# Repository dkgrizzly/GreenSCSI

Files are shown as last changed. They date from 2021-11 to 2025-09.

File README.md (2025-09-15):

# GreenSCSI
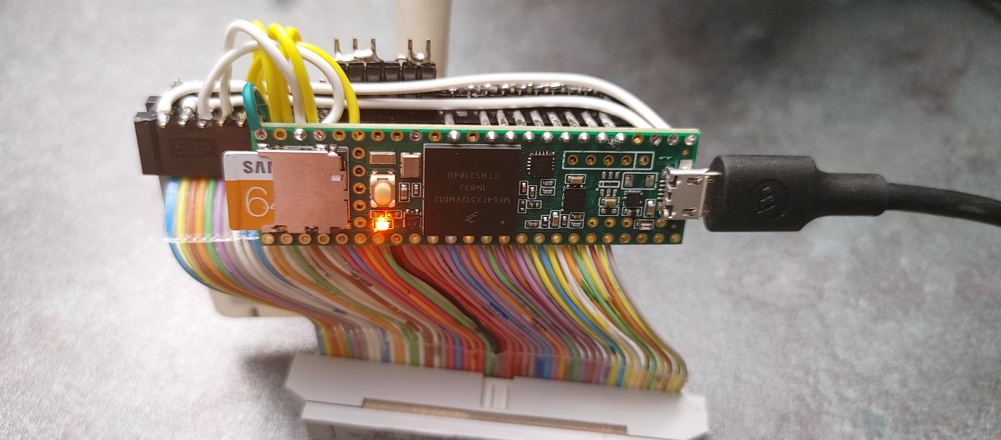
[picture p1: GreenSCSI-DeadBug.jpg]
DeadBug assembly of a Teensy 3.5 directly on a 50 pin SCSI header! GreenSCSI Teensy 3.5 Dead Bug


GreenSCSI, BlueSCSI & ArdSCSino are hardware that reproduce SCSI devices (hard disks) with Arduino like devices.

`GreenSCSI` created by https://github.com/dkgrizzly [dkgrizzly] is a fork of `BlueSCSI` which adds:

* Teensy 3.5 (Kinetis K64...) support
* Better LUN handling

`BlueSCSI` created by https://github.com/erichelgeson [erichelgeson] is a fork of `ArdSCSino-stm32`

`ArdSCSino-stm32` created by https://github.com/ztto/ArdSCSino-stm32 [ztto] is the STM32 version of `ArdSCSino`

`ArdSCSino` created by https://twitter.com/h_koma2 [Tambo (TNB Seisakusho)]

Build against LittleFS commit a061862589841627424170a12a246ce5660a4f0a if using Arduino 1.8.19 and Teensyduino 1.8.5

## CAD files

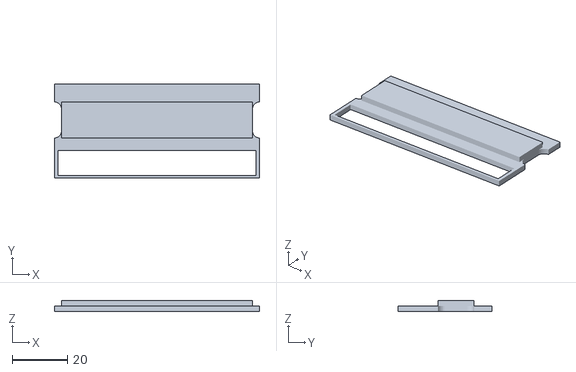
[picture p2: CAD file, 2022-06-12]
case/GreenSCSI-top.stl
74.0 x 34.0 x 4.00

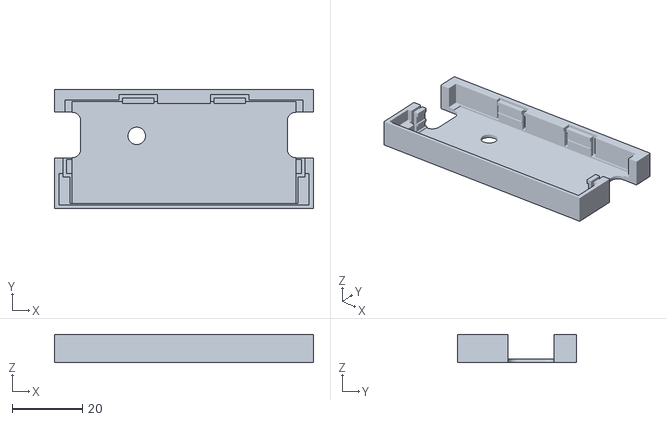
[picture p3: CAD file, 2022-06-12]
case/GreenSCSI-bottom.stl
74.0 x 34.0 x 8.00

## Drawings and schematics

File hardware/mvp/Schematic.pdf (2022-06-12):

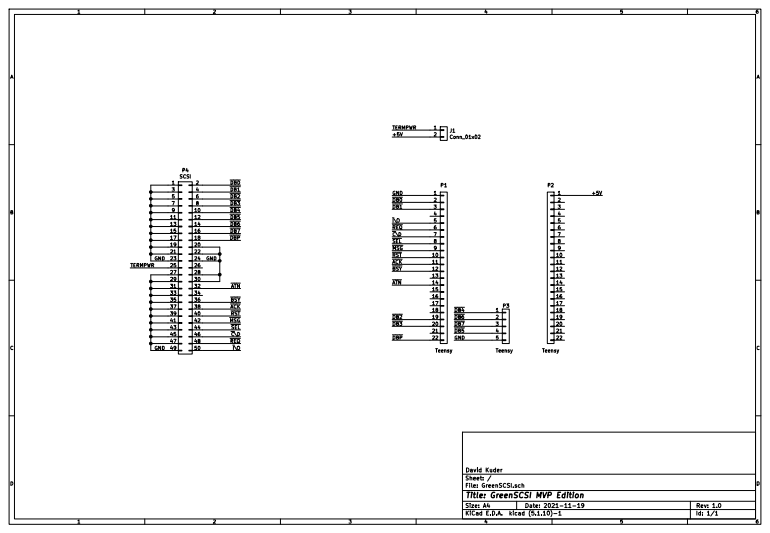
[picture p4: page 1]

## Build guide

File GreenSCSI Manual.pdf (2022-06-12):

# GreenSCSI

# Reference Manual

Revision 0001 - 1/1/2022
Copyright (C) 2022 David Kuder

## Thank you for your purchase of a GreenSCSI Kit!

## At a time when mainstream vendors have dropped commercial

support and products on the market were cost prohibitive,

## a community has sprung up to provide storage solutions on SCSI and other vintage disk interfaces. We’re glad to be part of that community and provide inexpensive options

for enthusiasts in need.

## GreenSCSI wouldn’t be here without the work of the

BlueSCSI, RaSCSI, TinySCSIEmu, and SCSI2SD projects.

Your support means that we can keep doing what we love,

## keeping old computers working and fun!

## -David Kuder

GreenSCSI | Preface

I

II

# Section 1 - Hardware Assembly

## Parts and Tools checklist | Page 1 Soldering the kit | Page 2

# Section 2 - Testing your GreenSCSI

## Loopback plug installation | Page 5 Test procedure | Page 6

# Section 3 - microSD Card Setup

## Formatting the microSD Card | Page 9 Interactive Configuration | Page 10 Configuration Reference | Page 11

# Appendix A - Troubleshooting

GreenSCSI | Table of Contents

# III

IV

With your GreenSCSI Kit you should have recieved the parts listed below. Please check your kit’s contents and make sure all parts are present.

❒ GreenSCSI Board
❒ Teensy 3.5
❒ 50 Pin SCSI Connector
❒ SCSI Loop-Back Test Plug

You will need some tools and materials to assemble the kit:

❒ Soldering Iron (Temperature controlled preferred)
❒ Solder (ChipQuik and sparkfun are two of our favorite brands) ❒ Isopropyl Alcohol (For removing flux after soldering)

Some items that will also come in handy:

❒ USB Micro-B Cable
❒ USB microSD Reader

Depending on which version of the kit you purchased, you may have recieved a microSD card preloaded with an example configuration and some blank drive images.

Section 3 in this manual details the creation of such a card for use with GreenSCSI, including the creation of blank disk images and configuration via greenscsi.cfg or the interactive console.

GreenSCSI | Hardware Assembly

Step 1.

Pre-heat your soldering iron. Typically a temperature of 320’C or 608’F is used.
Once your iron is at temperature it is a good idea to clean the tip with a brass sponge to remove any residue from previous jobs.
Step 2.

Use the included header pins to align the corners of the Teensy 3.5 board with the matching footprint on the GreenSCSI board. The pads on the back of the Teensy 3.5 should be aligned with the oblong cut outs in the GreenSCSI board and there should be no gap between the boards.

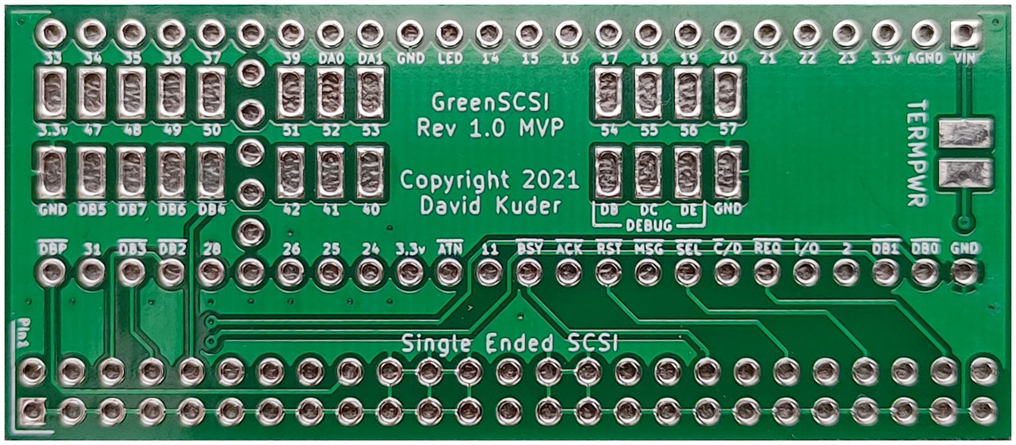
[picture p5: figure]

[ Picture 1 - GreenSCSI Board Bottom Side ]

Step 3.

When you have the pads aligned in the slots you can heat the pad and the slot with the iron and begin flowing in solder. You may need to carefully scrape the pad with your iron as you start for the solder to begin adhering to the pad. At a minimum you need to solder the connections labeled DB4, DB5, DB6, and DB7. Any locations labeled with only numbers are unused pins in the design which you are free to use for adding functionality to the GreenSCSI. You can reference the “Welcome to Teensy 3.5” card included in your kit for what functions are available on each pin.

[ Picture 2 - Soldering DB5 ]

GreenSCSI | Hardware Assembly

Step 4.

With the DB4 - DB7 pads soldered, you should now be able to remove the pins used to align the boards in step 2. Solder the remaining named locations starting with VIN and DBP working your way around to not create a concentration of heat in any one area. A 10 cm length of bare wire is included in the kit to make soldering of the through holes easier. Cut the wire flush after soldering each connection.

[ Picture 3 - Soldering DBP ]

Step 5.

Align the 50 pin male SCSI connector in the holes provided. Pin 1 on the SCSI connector is marked with an arrow and the alignment notch should face to the edge of the board.

[ Picture 4 - Soldering the SCSI connector ]

Next Section: Testing your GreenSCSI

GreenSCSI | Hardware Assembly
- ▶ ▶

You should now have an assembled GreenSCSI device, and are likely tempted to plug it in to your treasured vintage equipment - BUT WAIT! It is important to first test your GreenSCSI with the included LoopBack plug to ensure that all connections made during assembly are solid. This only takes a moment and saves you troubleshooting headaches later on.

[ Picture 5 - LoopBack installed ]

With the LoopBack plug installed and no microSD card inserted, connect your GreenSCSI to a modern computer with a USB Micro-B cable. Your computer should detect a USB Serial adapter and automatically configure it for use.

[ Picture 6 - USB Detection Bubble ]

GreenSCSI | Testing your GreenSCSI

Open up a terminal emulator and connect to the new serial port that was just installed. We recommend using Tera Term on Windows computers.

[ Picture 7 - Tera Term ]

Press ENTER on your keyboard and you should see a | / $ _ | prompt appear.
Type loopbacktest and press ENTER. The GreenSCSI firmware will run several tests to ensure that the SCSI bus connections are correct and free from any faults. When directed, remove the loopback plug and press ENTER to complete the final tests. You will get a test report similar to the one shown below.

[ Picture 8 - Loop Back Test Report ]

If all went well you should now be ready to move on to configuring your microSD card.
If there were any faults found, double check the soldering as directed by the test report.

Next Section: microSD card Setup

GreenSCSI | Testing your GreenSCSI
- ▶ ▶

Your GreenSCSI supports truly massive storage compared to the vintage systems you are likely to be using it with. The choice is yours as to the size of microSD card to use. We have tested 32GB, 64GB, 128GB, and 256GB cards from Samsung and found them to function well with the GreenSCSI hardware and firmware. In order to support disk images over 2GB in size, your microSD card should be formatted with the ExFAT filesystem.

Now that your card is formatted, you can create a greenscsi.cfg file using either the interactive console present in the firmware of the GreenSCSI device, or by hand with a text editor on your modern computer.

GreenSCSI | microSD card Setup

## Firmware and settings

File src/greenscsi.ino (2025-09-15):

/*  
 *  GreenSCSI
 *  Copyright (c) 2021  David Kuder
 *  
 *  Based on BlueSCSI
 *  Copyright (c) 2021  Eric Helgeson, Androda
 *  
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
 * This file incorporates work covered by the following copyright and  
 * permission notice:  
 *  
 *     Copyright (c) 2019 komatsu   
 *  
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
 *     THE SOFTWARE IS PROVIDED "AS IS" AND THE AUTHOR DISCLAIMS ALL  
 *     WARRANTIES WITH REGARD TO THIS SOFTWARE INCLUDING ALL IMPLIED  
 *     WARRANTIES OF MERCHANTABILITY AND FITNESS. IN NO EVENT SHALL THE  
 *     AUTHOR BE LIABLE FOR ANY SPECIAL, DIRECT, INDIRECT, OR  
 *     CONSEQUENTIAL DAMAGES OR ANY DAMAGES WHATSOEVER RESULTING FROM LOSS  
 *     OF USE, DATA OR PROFITS, WHETHER IN AN ACTION OF CONTRACT,  
 *     NEGLIGENCE OR OTHER TORTIOUS ACTION, ARISING OUT OF OR IN  
 *     CONNECTION WITH THE USE OR PERFORMANCE OF THIS SOFTWARE.  
 */

#include <Arduino.h> // For Platform.IO
#include <SPI.h>
#include <LittleFS.h>
#include <SdFat.h>
#include "sdios.h"
#include "config.h"
#include "scsi_defs.h"
#include "cmd.h"

// SDFAT
SdFs sd;
LittleFS_Program lfs;


struct part_s {
  uint8_t boot;
  uint8_t beginCHS[3];
  uint8_t type;
  uint8_t endCHS[3];
  uint32_t firstSector;
  uint32_t totalSectors;
} __attribute__((packed));
typedef struct part_s part_t;
//-----------------------------------------------------------------------------
struct mbr_s {
  uint8_t   bootCode[446];
  part_t part[4];
  uint8_t   signature[2];
} __attribute__((packed));
typedef struct mbr_s mbr_t;

boolean debuglog = 0;

#if DEBUG == 1
#define LOG(XX)      if(debuglog) Serial.print(XX)
#define LOGHEX2(XX)  if(debuglog) Serial.printf("%02x", XX)
#define LOGHEX4(XX)  if(debuglog) Serial.printf("%04x", XX)
#define LOGHEX6(XX)  if(debuglog) Serial.printf("%06x", XX)
#define LOGHEX8(XX)  if(debuglog) Serial.printf("%08x", XX)
#define LOGN(XX)     if(debuglog) Serial.println(XX)
#define LOGHEX2N(XX) if(debuglog) Serial.printf("%02x\r\n", XX)
#define LOGHEX4N(XX) if(debuglog) Serial.printf("%04x\r\n", XX)
#define LOGHEX6N(XX) if(debuglog) Serial.printf("%06x\r\n", XX)
#define LOGHEX8N(XX) if(debuglog) Serial.printf("%08x\r\n", XX)
#elif DEBUG == 2
#define LOG(XX)      LOG_FILE.print(XX); LOG_FILE.sync();
#define LOGHEX2(XX)  LOG_FILE.printf("%02x", XX); LOG_FILE.sync();
#define LOGHEX4(XX)  LOG_FILE.printf("%04x", XX); LOG_FILE.sync();
#define LOGHEX6(XX)  LOG_FILE.printf("%06x", XX); LOG_FILE.sync();
#define LOGHEX8(XX)  LOG_FILE.printf("%08x", XX); LOG_FILE.sync();
#define LOGN(XX)     LOG_FILE.println(XX); LOG_FILE.sync();
#define LOGHEX2N(XX) LOG_FILE.printf("%02x\r\n", XX); LOG_FILE.sync();
#define LOGHEX4N(XX) LOG_FILE.printf("%04x\r\n", XX); LOG_FILE.sync();
#define LOGHEX6N(XX) LOG_FILE.printf("%06x\r\n", XX); LOG_FILE.sync();
#define LOGHEX8N(XX) LOG_FILE.printf("%08x\r\n", XX); LOG_FILE.sync();
#else
#define LOG(XX)      //Serial.print(XX)
#define LOGHEX2(XX)  //Serial.printf("%02x", XX)
#define LOGHEX4(XX)  //Serial.printf("%04x", XX)
#define LOGHEX6(XX)  //Serial.printf("%06x", XX)
#define LOGHEX8(XX)  //Serial.printf("%08x", XX)
#define LOGN(XX)     //Serial.println(XX)
#define LOGHEX2N(XX) //Serial.printf("%02x\r\n", XX)
#define LOGHEX4N(XX) //Serial.printf("%04x\r\n", XX)
#define LOGHEX6N(XX) //Serial.printf("%06x\r\n", XX)
#define LOGHEX8N(XX) //Serial.printf("%08x\r\n", XX)
#endif

#define DB0       0     // SCSI:DB0  Port B Bit 16
#define DB1       1     // SCSI:DB1  Port B Bit 17
#define DB2       29    // SCSI:DB2  Port B Bit 18
#define DB3       30    // SCSI:DB3  Port B Bit 19
#define DB4       43    // SCSI:DB4  Port B Bit 20
#define DB5       46    // SCSI:DB5  Port B Bit 21
#define DB6       44    // SCSI:DB6  Port B Bit 22
#define DB7       45    // SCSI:DB7  Port B Bit 23
#define DBP       32    // SCSI:DBP  Port B Bit 11

#define ATN       12    // SCSI:ATN  Port C Bit 7
#define BSY       10    // SCSI:BSY  Port C Bit 4
#define ACK       9     // SCSI:ACK  Port C Bit 3
#define RST       8     // SCSI:RST  Port D Bit 3
#define MSG       7     // SCSI:MSG  Port D Bit 2
#define SEL       6     // SCSI:SEL  Port D Bit 4
#define CD        5     // SCSI:C/D  Port D Bit 7
#define REQ       4     // SCSI:REQ  Port A Bit 13
#define IO        3     // SCSI:I/O  Port A Bit 12

#define SD_CS     BUILTIN_SDCARD      // SDCARD:CS
#define LED       13     // LED  Port C Bit 5

// LED control
#define LED_ON()       { GPIOC_PSOR = (1 << 5); }
#define LED_OFF()      { GPIOC_PCOR = (1 << 5); }

#define SET_REQ_ACTIVE()    { GPIOA_PCOR = (1 << 13); }
#define SET_REQ_INACTIVE()  { GPIOA_PSOR = (1 << 13); }
//#define SET_MSG_ACTIVE()    { GPIOD_PCOR = (1 << 2); __asm__("nop""\n\t""nop""\n\t"); }
//#define SET_MSG_INACTIVE()  { GPIOD_PSOR = (1 << 2); __asm__("nop""\n\t""nop""\n\t"); }
//#define SET_CD_ACTIVE()     { GPIOD_PCOR = (1 << 7); __asm__("nop""\n\t""nop""\n\t"); }
//#define SET_CD_INACTIVE()   { GPIOD_PSOR = (1 << 7); __asm__("nop""\n\t""nop""\n\t"); }
//#define SET_IO_ACTIVE()     { GPIOA_PCOR = (1 << 12); __asm__("nop""\n\t""nop""\n\t"); }
//#define SET_IO_INACTIVE()   { GPIOA_PSOR = (1 << 12); __asm__("nop""\n\t""nop""\n\t"); }

//#define SET_REQ_ACTIVE()     { pinMode(REQ, OUTPUT_OPENDRAIN);  digitalWrite(REQ, LOW); }
//#define SET_REQ_INACTIVE()   { digitalWrite(REQ, HIGH); pinMode(REQ, INPUT); }
#define SET_MSG_ACTIVE()     { pinMode(MSG, OUTPUT_OPENDRAIN); digitalWrite(MSG, LOW); }
#define SET_MSG_INACTIVE()   { digitalWrite(MSG, HIGH); pinMode(MSG, INPUT); }
#define SET_CD_ACTIVE()     { pinMode(CD, OUTPUT_OPENDRAIN);  digitalWrite(CD, LOW); }
#define SET_CD_INACTIVE()   { digitalWrite(CD, HIGH); pinMode(CD, INPUT); }
#define SET_IO_ACTIVE()     { pinMode(IO, OUTPUT_OPENDRAIN); digitalWrite(IO, LOW); }
#define SET_IO_INACTIVE()   { digitalWrite(IO, HIGH); pinMode(IO, INPUT); }
//#define SET_BSY_ACTIVE()     { pinMode(BSY, OUTPUT_OPENDRAIN); digitalWrite(BSY, LOW); }
//#define SET_BSY_INACTIVE()   { digitalWrite(BSY, HIGH); pinMode(BSY, INPUT); }

#define SET_BSY_ACTIVE()   { GPIOC_PCOR = (1 << 4); __asm__("nop""\n\t"); }
#define SET_BSY_INACTIVE() { GPIOC_PSOR = (1 << 4); }

#define GET_ACK() (!(GPIOC_PDIR & (1 << 3)))
#define GET_ATN() (!(GPIOC_PDIR & (1 << 7)))
#define GET_BSY() (!(GPIOC_PDIR & (1 << 4)))
#define GET_RST() (!(GPIOD_PDIR & (1 << 3)))
#define GET_SEL() (!(GPIOD_PDIR & (1 << 4)))

// Initiator Mode
#define SET_ACK_ACTIVE()   { GPIOC_PCOR = (1 << 3); __asm__("nop""\n\t"); }
#define SET_ACK_INACTIVE() { GPIOC_PSOR = (1 << 3); }
#define SET_ATN_ACTIVE()   { GPIOC_PCOR = (1 << 7); __asm__("nop""\n\t"); }
#define SET_ATN_INACTIVE() { GPIOC_PSOR = (1 << 7); }
#define SET_RST_ACTIVE()   { GPIOD_PCOR = (1 << 3); __asm__("nop""\n\t"); }
#define SET_RST_INACTIVE() { GPIOD_PSOR = (1 << 3); }
#define SET_SEL_ACTIVE()   { GPIOD_PCOR = (1 << 4); __asm__("nop""\n\t"); }
#define SET_SEL_INACTIVE() { GPIOD_PSOR = (1 << 4); }

#define GET_MSG() (!(GPIOD_PDIR & (1 << 2)))
#define GET_CD()  (!(GPIOD_PDIR & (1 << 7)))
#define GET_IO()  (!(GPIOA_PDIR & (1 << 12)))
#define GET_REQ() (!(GPIOA_PDIR & (1 << 13)))

// Turn on the output only for BSY
// BSY,REQ,MSG,CD,IO Turn on the output (no change required for OD)
#define SCSI_TARGET_ACTIVE()   { }
// BSY,REQ,MSG,CD,IO Turn off output
#define SCSI_TARGET_INACTIVE() { SCSI_DB_INPUT(); SET_REQ_INACTIVE(); SET_MSG_INACTIVE(); SET_CD_INACTIVE(); SET_IO_INACTIVE(); SET_BSY_INACTIVE(); }

#define SCSI_INITIATOR_INACTIVE() { SCSI_DB_INPUT(); SET_SEL_INACTIVE(); SET_ACK_INACTIVE(); SET_ATN_INACTIVE(); SET_RST_INACTIVE(); }

#define SCSI_DB_MASK 0x00ff0800


// HDImage file
#define HDIMG_ID_POS  2                 // Position to embed ID number
#define HDIMG_LUN_POS 3                 // Position to embed LUN numbers
#define HDIMG_BLK_POS 5                 // Position to embed block size numbers
#define MAX_FILE_PATH 32                // Maximum file name length

typedef struct m_sense_s {
  uint8_t     m_key;
  uint8_t     m_code;
  uint8_t     m_key_specific[4];
} msense_t;

typedef void (*CommandHandler_t)();
CommandHandler_t m_badlunhandler[256];

// VirtualDevice
typedef struct VirtualDevice_s
{
  boolean     m_enabled;
  uint8_t     m_id;
  uint8_t     m_lun;
  uint8_t     m_type;                 // Device Type
  char        m_filename[MAX_FILE_PATH+1];
  FsFile      m_file;                 // File object
  uint64_t    m_fileSize;             // File size
  uint8_t     m_sectors;
  uint8_t     m_heads;
  uint32_t    m_cylinders;
  size_t      m_blocksize;            // SCSI BLOCK size
  uint32_t    m_firstSector;          // First sector for partition
  boolean     m_rawPart;              // Raw Partition (True) or Image File (False)
#if SUPPORT_TAPE
  size_t      m_filemarks;            // Tape position counter (file marks since BOM)
#endif
  uint8_t     m_inquiryresponse[SCSI_INQUIRY_RESPONSE_SIZE];
  CommandHandler_t m_handler[256];
  msense_t    m_sense;
  uint16_t    m_quirks;
} VirtualDevice_t;

VirtualDevice_t  m_vdev[NUM_VDEV];    // Maximum number
uint8_t       m_vdevcnt = 0;          // Number of allocated vdevs
uint8_t       m_vdevmap[NUM_SCSIID][NUM_SCSILUN]; // Map ID/LUN to a vdev

volatile bool m_isBusReset = false;   // Bus reset

uint8_t       scsi_id_mask;           // Mask list of responding SCSI IDs
uint8_t       m_id;                   // Currently responding SCSI-ID
uint8_t       m_lun;                  // Logical unit number currently responding
uint8_t       m_sts;                  // Status uint8_t
uint8_t       m_msg;                  // Message uint8_ts
VirtualDevice_t *m_sel;               // VirtualDevice for current SCSI-ID, LUN
uint8_t       m_buf[MAX_BLOCKSIZE+1]; // General purpose buffer + overrun fetch
int           m_msc;
uint8_t       m_msb[256];             // Command storage uint8_ts
uint8_t       m_cmdlen;
uint8_t       m_cmd[12];
uint8_t       m_responsebuffer[256];
uint16_t      default_quirks = (SUPPORT_SASI_DEFAULT ? QUIRKS_SASI : 0) | (SUPPORT_APPLE_DEFAULT ? QUIRKS_APPLE : 0);
uint16_t ledbits = 0;
uint8_t ledbit = 0;

uint8_t cardMBR[512];

typedef enum {
  PHASE_BUSFREE = 0,
  PHASE_SELECTION,
  PHASE_MESSAGEOUT,
  PHASE_COMMAND,
  PHASE_STATUSIN,
  PHASE_MESSAGEIN,
} phase_t;
phase_t       m_phase = PHASE_BUSFREE;

// Log File
#define VERSION "1.4-20230529"
#if DEBUG == 2
#define LOG_FILENAME "LOG.txt"
FsFile LOG_FILE;
#endif


void onBusReset(void);
void initFileLog(void);
void finalizeFileLog(void);

/*
 * IO read.
 */
inline uint8_t readIO(void)
{
  // Port input data register
  uint32_t ret = ~GPIOB_PDIR;
  //uint8_t bret = ret >> 16;
#if READ_PARITY_CHECK
  if((db_bsrr[bret] ^ ret) & 0x0800)
    m_sts |= 0x01; // parity error
#endif

  return ret >> 16; //bret;
}

boolean OpenImage(VirtualDevice_t *h, const char *image_name)
{
  h->m_fileSize = 0;
  h->m_file = sd.open(image_name, O_RDWR);
  if(h->m_file.isOpen()) {
    h->m_fileSize = h->m_file.size();
    h->m_cylinders = (uint32_t)((uint64_t)h->m_fileSize / ((uint64_t)h->m_blocksize * (uint64_t)h->m_heads * (uint64_t)h->m_sectors));

    return true; // File opened
  }
  return false;
}

#if SUPPORT_DISK or SUPPORT_OPTICAL
/*
 * Open HDD or CDROM image file
 */
boolean OpenDiskImage(VirtualDevice_t *h, const char *image_name, int blocksize)
{
  if(!strncmp(image_name, "/tgts/", 6)) {
    LOGN("/tgts/ path is not supported for disk images.");
    return false;
  }

  if(!strncmp(image_name, "/vdevs/", 7)) {
    LOGN("/vdevs/ path is not supported for disk images.");
    return false;
  }

  if(!strncmp(image_name, "/diag/", 6)) {
    LOGN("/diag/ path is not supported for disk images.");
    return false;
  }

  if(!strncmp(image_name, "/nv/", 4)) {
    LOGN("/nv/ path is not supported for disk images.");
    return false;
  }

  h->m_rawPart = false;

  if(!strncmp(image_name, "/raw/part", 9)) {
    int partIndex = image_name[9] - '0';
    mbr_t *mbr = (mbr_t *)cardMBR;
    if((partIndex < 0) || (partIndex > 3)) {
      LOGN("partition index is outside the allowed range.");
      return false;
    }

    sd.card()->readSector(0, cardMBR);
    if(mbr->part[partIndex].type != 0x87) {
      LOGN("partition is of the wrong type.");
      return false;
    }
    
    h->m_blocksize = blocksize;
    h->m_fileSize = ((uint64_t)mbr->part[partIndex].totalSectors) * ((uint64_t)512);
    h->m_cylinders = (uint32_t)((uint64_t)h->m_fileSize / ((uint64_t)h->m_blocksize * (uint64_t)h->m_heads * (uint64_t)h->m_sectors));
    h->m_rawPart = true;
    h->m_firstSector = mbr->part[partIndex].firstSector;

    LOG(" Imagefile: ");
    LOG(image_name);
    LOG(" / ");
    LOG(h->m_fileSize / h->m_blocksize);
    LOG(" sectors / ");
    LOG(h->m_fileSize / 1024);
    LOG(" KiB / ");
    LOG(h->m_fileSize / 1024 / 1024);
    LOGN(" MiB");
    return true; // File opened
  }

  if(!strncmp(image_name, "/sd/", 4))
    image_name += 3;

  h->m_fileSize = 0;
  h->m_blocksize = blocksize;
  h->m_file = sd.open(image_name, O_RDWR);
  if(h->m_file.isOpen())
  {
    h->m_fileSize = h->m_file.size();
    h->m_cylinders = (uint32_t)((uint64_t)h->m_fileSize / ((uint64_t)h->m_blocksize * (uint64_t)h->m_heads * (uint64_t)h->m_sectors));
    LOG(" Imagefile: ");
    LOG(image_name);
    if(h->m_fileSize>0)
    {
      // check blocksize dummy file
      LOG(" / ");
      LOG(h->m_fileSize / h->m_blocksize);
      LOG(" sectors / ");
      LOG(h->m_fileSize / 1024);
      LOG(" KiB / ");
      LOG(h->m_fileSize / 1024 / 1024);
      LOGN(" MiB");
      return true; // File opened
    }
    else
    {
      h->m_file.close();
      h->m_fileSize = h->m_blocksize = 0; // no file
      LOGN(" FileSizeError");
    }
  }
  return false;
}
#endif /* SUPPORT_DISK or SUPPORT_OPTICAL */

#if SUPPORT_TAPE
/*
 * Open Tape image file
 */
boolean OpenTapeImage(VirtualDevice_t *h, const char *image_name)
{
  if(!strncmp(image_name, "/tgts/", 6)) {
    LOGN("/tgts/ path is not supported for tape images.");
    return false;
  }

  if(!strncmp(image_name, "/vdevs/", 7)) {
    LOGN("/vdevs/ path is not supported for tape images.");
    return false;
  }

  if(!strncmp(image_name, "/diag/", 6)) {
    LOGN("/diag/ path is not supported for tape images.");
    return false;
  }

  if(!strncmp(image_name, "/nv/", 4)) {
    LOGN("/nv/ path is not supported for tape images.");
    return false;
  }

  if(!strncmp(image_name, "/sd/", 4))
    image_name += 3;

  h->m_fileSize = 0;
  h->m_blocksize = 0;
  h->m_filemarks = 0;
  h->m_file = sd.open(image_name, O_RDWR);
  if(h->m_file.isOpen()) {
    h->m_fileSize = h->m_file.size();
    h->m_blocksize = 1024;
    LOG(" Imagefile: ");
    LOG(image_name);
    if(h->m_fileSize>0) {
      // check blocksize dummy file
      LOG(" / ");
      LOG(h->m_fileSize / 1024);
      LOG(" KiB / ");
      LOG(h->m_fileSize / 1024 / 1024);
      LOGN(" MiB");
    } else {
      LOGN(" / Blank Tape");
    }
    return true; // File opened
  }
  return false;
}
#endif /* SUPPORT_TAPE */
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
void loop() {
  if(ledbits) {
    if(ticktock > 250) {
      if(ledbits & (1<<ledbit)) {
        LED_ON();
      } else {
        LED_OFF();
      }

      ledbit++;
      ledbit &= 0xf;

      ticktock = 0;
    }

    // Cancel ID error indication if we have any IDs enabled
    if((ledbit == 0) && (ledbits == 0b0000000000101010) && (scsi_id_mask != 0))
      ledbits = 0;
  }
  if(!ledbits) {
    if(scsi_id_mask == 0) ledbits = 0b0000000000101010;
  }

  switch(m_phase) {
    default:
    case PHASE_BUSFREE:
      BusFreePhaseHandler();
      break;
    case PHASE_SELECTION:
      //SelectionPhaseHandler();

      // Do other work while we wait for SEL to be asserted
      cmdPoll();
      break;
    case PHASE_MESSAGEOUT:
      MessageOutPhaseHandler();
      break;
    case PHASE_COMMAND:
      CommandPhaseHandler();
      break;
    case PHASE_STATUSIN:
      StatusInPhaseHandler();
      break;
    case PHASE_MESSAGEIN:
      MessageInPhaseHandler();
      break;
  }
}

void SelectionPhaseISR() {
  m_msg = 0;

  // Wait until RST = H, BSY = H, SEL = L
  while(GET_BSY() || GET_RST()) {
    if(!GET_SEL()) return;
  }

  // BSY+ SEL-
  // If the ID to respond is not driven, wait for the next
  uint8_t scsiid = readIO() & scsi_id_mask;
  if(scsiid == 0) {
    // We were not selected, treat this as an abort and cancel any transactions we can.
    m_isBusReset = true;
    SCSI_TARGET_INACTIVE();
    m_phase = PHASE_BUSFREE;
    return;
  }
  LOG("Selection ");
  m_isBusReset = false;
  // Set BSY to-when selected
  SET_BSY_ACTIVE();     // Turn only BSY output ON, ACTIVE

  // Ask for a TARGET-ID to respond
#if USE_DB2ID_TABLE
  m_id = db2scsiid[scsiid];
#else
  for(m_id=7;m_id>=0;m_id--)
    if(scsiid & (1<<m_id)) break;
#endif
  m_lun = 0xff;

  //LOGN("Wait !SEL");
  // Wait until SEL becomes inactive
  while(GET_SEL() && !GET_BSY()) {
    if(m_isBusReset) {
      LOGN("!SEL");
      m_phase = PHASE_BUSFREE;
      return;
    }
  }
  m_phase = PHASE_MESSAGEOUT;
}

void MessageOutPhaseHandler() {
  //LOGN("ACTIVE");
  SCSI_TARGET_ACTIVE();  // (BSY), REQ, MSG, CD, IO output turned on
  //  
  if(GET_ATN()) {
    //LOGN("ATN");
    bool syncenable = false;
    int syncperiod = 50;
    int syncoffset = 0;
    int loopWait = 0;
    m_msc = 0;
    memset(m_msb, 0x00, sizeof(m_msb));
    while(GET_ATN() && loopWait < 255) {
      MsgOut2();
      loopWait++;
    }
    for(int i = 0; i < m_msc; i++) {
      // ABORT
      if (m_msb[i] == 0x06) {
        m_phase = PHASE_BUSFREE;
        return;
      }
      // BUS DEVICE RESET
      if (m_msb[i] == 0x0C) {
        syncoffset = 0;
        m_phase = PHASE_BUSFREE;
        return;
      }
      // IDENTIFY message overrides LUN IDs specified in commands.
      if (m_msb[i] & 0x80) {
        m_lun = m_msb[i] & 0x07;
      }
      // Extended message
      if (m_msb[i] == 0x01) {
        // Check only when synchronous transfer is possible
        if (!syncenable || m_msb[i + 2] != 0x01) {
          MsgIn2(0x07);
          break;
        }
        // Transfer period factor(50 x 4 = Limited to 200ns)
        syncperiod = m_msb[i + 3];
        if (syncperiod > 50) {
          syncperiod = 50;
        }
        // REQ/ACK offset(Limited to 16)
        syncoffset = m_msb[i + 4];
        if (syncoffset > 16) {
          syncoffset = 16;
        }
        // STDR response message generation
        MsgIn2(0x01);
        MsgIn2(0x03);
        MsgIn2(0x01);
        MsgIn2(syncperiod);
        MsgIn2(syncoffset);
        break;
      }
    }
  }
  m_phase = PHASE_COMMAND;
}

void CommandPhaseHandler() {
  LOG("Command:");
  SET_MSG_INACTIVE();
  SET_CD_ACTIVE();
  SET_IO_INACTIVE();
  
  m_cmd[0] = readHandshake();
  if(m_isBusReset) {
    m_phase = PHASE_BUSFREE;
    return;
  }
  LOGHEX2(m_cmd[0]);

  // Command length selection, reception
  static const int cmd_class_len[8]={6,10,10,6,6,12,6,6};
  m_cmdlen = cmd_class_len[m_cmd[0] >> 5];

  // Receive the remaining command bytes
  for(int i = 1; i < m_cmdlen; i++ ) {
    m_cmd[i] = readHandshake();
    LOG(":");
    LOGHEX2(m_cmd[i]);
    if(m_isBusReset) {
      m_phase = PHASE_BUSFREE;
      return;
    }
  }

  // LUN confirmation
  m_sts = m_cmd[1]&0xe0;      // Preset LUN in status byte if not specified by Identify Message
  if(m_lun == 0xff) m_lun = (m_sts>>5);

  // HDD Image selection
  m_sel = (VirtualDevice_t *)0; // None
  if( (m_lun < NUM_SCSILUN) )
  {
    uint8_t v = m_vdevmap[m_id][m_lun];
    if(v < NUM_VDEV) {
      m_sel = &(m_vdev[v]); // There is an image
      if(!m_sel->m_enabled)
        m_sel = (VirtualDevice_t *)0;       // Image absent
    }
  }
  
  LOG(":ID ");
  LOG(m_id);
  LOG(":LUN ");
  LOG(m_lun);

  LOG(" ");

  if(!m_sel) {
    m_badlunhandler[m_cmd[0]]();
  } else {
    m_sel->m_handler[m_cmd[0]]();
  }
}

void ConfigureBadLunHandlers() {
  for(int c = 0; c < 256; c++)
    m_badlunhandler[c] = &BadLunCommandHandler;

  m_badlunhandler[0x03] = &RequestSenseCommandHandler;
  m_badlunhandler[0x12] = &InquiryCommandHandler;
}

void StatusInPhaseHandler() {
  //LOGN("Sts");
  SET_MSG_INACTIVE();
  SET_CD_ACTIVE();
  SET_IO_ACTIVE();
  writeHandshake(m_sts);
  m_phase = PHASE_MESSAGEIN;
}

void MessageInPhaseHandler() {
  //LOGN("MsgIn");
  SET_MSG_ACTIVE();
  SET_CD_ACTIVE();
  SET_IO_ACTIVE();
  writeHandshake(m_msg);
  m_phase = PHASE_BUSFREE;
}

void BusFreePhaseHandler() {
  //LOGN("BusFree");
  // Release control of the bus.
  SCSI_TARGET_INACTIVE();
  // Clear the reset pending flag.
  m_isBusReset = false;
  // Reset back to waiting for selection phase.
  m_phase = PHASE_SELECTION;
}

typedef struct SelfTestPins_s {
  int A;
  int B;
  int pA;
  int pB;
  char nA[4];
  char nB[4];
} SelfTestPins_t;

SelfTestPins_t SelfTestPins[] = {
  { IO, DB0, 50, 2, "I/O", "DB0" },
  { REQ, DB1, 48, 4, "REQ", "DB1" },
  { CD, DB2, 46, 6, "C/D", "DB2" },
  { SEL, DB3, 44, 8, "SEL", "DB3" },
  { MSG, DB4, 42, 10, "MSG", "DB4" },
  { RST, DB5, 50, 12, "RST", "DB5" },
  { ACK, DB6, 38, 14, "ACK", "DB6" },
  { BSY, DB7, 36, 16, "BSY", "DB7" },
  { ATN, DBP, 32, 18, "ATN", "DBP" },
};

void SelfTest(int argc, char **argv) {
  int i, x;
  char c;

  Serial.printf("Are you sure you wish to run the self test? ");
  for(;;) {
    if (Serial.available()) {
      c = Serial.read();
      switch(c) {
        default:
          return;
        case 'y': case 'Y':
          goto ConnectHarness;
      }
    }
  }

ConnectHarness:
  // Clear any extra characters
  while (Serial.available()) {
    c = Serial.read();
  }

  // Disable normal operation and prepare the self test.
  detachInterrupt(RST);
  detachInterrupt(SEL);

  Serial.printf("Self Test starting...\r\n");

  // Delay for 3 seconds
  delay(3000);

  while (Serial.available()) {
    c = Serial.read();
  }

  Serial.printf("Connect the Loopback test adapter and press Enter.");
  for(;;) {
    if (Serial.available()) {
      c = Serial.read();
      switch(c) {
        case 0xA: case 0xD:
          goto ExecuteSelfTest;
      }
    }
  }
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

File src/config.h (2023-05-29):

#ifndef __CONFIG_H
#define __CONFIG_H

#define DEBUG                  1          // 0:No debug information output (Faster by 2-3x+)
                                          // 1: Debug information output to USB Serial
                                          // 2: Debug information output to LOG.txt (slow)

#define SYNCHRO                false      // Support Synchronous mode.
#define ACK_INTERRUPTS         false
#define READ_SPEED_OPTIMIZE    true       // 
#define WRITE_SPEED_OPTIMIZE   true       // 
#define READ_SPEED_OPTIMIZE_RAW    true       // 
#define WRITE_SPEED_OPTIMIZE_RAW   true       // 
#define USE_DB2ID_TABLE        true       // Use table to get ID from SEL-DB

// SCSI config
#define NUM_SCSIID             8          // Maximum number of supported SCSI-IDs (The minimum is 1)
#define NUM_SCSILUN            8          // Maximum number of LUNs supported     (The minimum is 1)
#define NUM_VDEV               16         // Maximum number of VDEVs supported    (The minimum is 1)

#define READ_PARITY_CHECK      0          // Perform read parity check (unverified)

// HDD format
#define MAX_BLOCKSIZE          (1 << 15)  // Maximum BLOCK size (2048 to 8192 tested, 16384 had issues)

#define SCSI_INQUIRY_RESPONSE_SIZE 96
extern uint8_t SCSI_INQUIRY_RESPONSE[][SCSI_INQUIRY_RESPONSE_SIZE];

// Supported Device Types
#define SUPPORT_DISK           true
#define SUPPORT_OPTICAL        true
#define SUPPORT_TAPE           false
#define SUPPORT_MO             false
#define SUPPORT_INITIATOR      true
#define SUPPORT_CONTROL        true

// Compatibility Settings
#define SUPPORT_SASI           false      // Enable SASI compatiblity for Sharp X68000
#define SUPPORT_SASI_DEFAULT   false      // Turn it on by default
#define SUPPORT_APPLE          true
#define SUPPORT_APPLE_DEFAULT  false

#endif /* __CONFIG_H */

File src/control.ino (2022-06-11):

#include "config.h"
#include "scsi_defs.h"

#if SUPPORT_CONTROL
/*
 * RECEIVE Command processing.
 */
void onControlReceiveCommand(uint32_t adds, uint32_t len)
{
  LOG("-R ");
  LOGHEX4N(len);

  if(!m_sel) {
    m_sts |= STATUS_CHECK;
    m_phase = PHASE_STATUSIN;
    return;
  }
  
  switch(m_cmd[1] & 0x3) {
    case 0:
      if(len == 0) return;
      break;
    case 1: // Fixed
      break;
    case 2: // SILI
      break;
    case 3: // Illegal Request
      m_sts = 0x02;
      m_sel->m_sense.m_key = ILLEGAL_REQUEST;
      m_sel->m_sense.m_code = INVALID_FIELD_IN_CDB;       /* "Invalid field in CDB" */
      m_sel->m_sense.m_key_specific[0] = ERROR_IN_OPCODE;  /* "Error in Byte 1" */
      m_sel->m_sense.m_key_specific[1] = 0x00;
      m_sel->m_sense.m_key_specific[2] = 0x01;
      m_phase = PHASE_STATUSIN;
      return;
  }

  LED_ON();
  writeDataPhase(len, m_responsebuffer);
  LED_OFF();

  m_phase = PHASE_STATUSIN;
}

/*
 * SEND Command processing.
 */
void onControlSendCommand(uint32_t adds, uint32_t len)
{
  LOG("-W ");
  LOGHEX4N(len);
  
  if(!m_sel) {
    m_sts |= STATUS_CHECK;
    m_phase = PHASE_STATUSIN;
    return;
  }
  if(len > MAX_BLOCKSIZE) {
      m_sel->m_sense.m_key = ILLEGAL_REQUEST;
      m_sel->m_sense.m_code = INVALID_FIELD_IN_CDB;    /* "Invalid field in CDB" */
      m_sel->m_sense.m_key_specific[0] = ERROR_IN_OPCODE;  /* "Error in Byte 4" */
      m_sel->m_sense.m_key_specific[1] = 0x00;
      m_sel->m_sense.m_key_specific[2] = 0x04;
      m_sts |= STATUS_CHECK;
      m_phase = PHASE_STATUSIN;
      return;
  }

  LED_ON();
  readDataPhase(len, m_responsebuffer);  
  LED_OFF();

  m_phase = PHASE_STATUSIN;
}

void ControlReceive6CommandHandler() {
  LOG("[Receive6]");
  onControlReceiveCommand((((uint32_t)m_cmd[1] & 0x1F) << 16) | ((uint32_t)m_cmd[2] << 8) | m_cmd[3], (m_cmd[4] == 0) ? 0x100 : m_cmd[4]);
}

void ControlSend6CommandHandler() {
  LOG("[Send6]");
  onControlSendCommand((((uint32_t)m_cmd[1] & 0x1F) << 16) | ((uint32_t)m_cmd[2] << 8) | m_cmd[3], (m_cmd[4] == 0) ? 0x100 : m_cmd[4]);
}

void ConfigureControlHandlers(VirtualDevice_t *vdev) {
  for(int c = 0; c < 256; c++)
    vdev->m_handler[c] = &UnknownCommandHandler;

  vdev->m_handler[CMD_TEST_UNIT_READY]               = &TestUnitCommandHandler;
  vdev->m_handler[CMD_REQUEST_SENSE]                 = &RequestSenseCommandHandler;
  vdev->m_handler[CMD_READ6]                         = &ControlReceive6CommandHandler;
  vdev->m_handler[CMD_WRITE6]                        = &ControlSend6CommandHandler;
  vdev->m_handler[CMD_INQUIRY]                       = &InquiryCommandHandler;
  vdev->m_handler[CMD_SEND_DIAGNOSTIC]               = &SendDiagnosticCommandHandler;
}

// If config file exists, read the first three lines and copy the contents.
// File must be well formed or you will get junk in the SCSI Vendor fields.
void ConfigureControl(VirtualDevice_t *vdev, const char *image_name) {
  for(int i = 0; SCSI_INQUIRY_RESPONSE[i][0] != 0xff; i++) {
    if(SCSI_INQUIRY_RESPONSE[i][0] == DEV_PROCESSOR) {
      memcpy(vdev->m_inquiryresponse, SCSI_INQUIRY_RESPONSE[i], SCSI_INQUIRY_RESPONSE_SIZE);
      break;
    }
  }

  vdev->m_type = DEV_PROCESSOR;
  ConfigureControlHandlers(vdev);
}
#endif

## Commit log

2021-11-19 Update and rename BlueSCSI.cpp to GreenSCSI.ino
    LUN Enhancement, Teensy 3.5 changes.
2021-11-22 This commit is seemingly stable with transfer speeds around 1.5MB/s - 1.6MB/s, equal to speeds obtained from TinySCSIEmu with the NCR5380 PHY. Successfully booted OpenVMS and Digital UNIX on an DEC A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
    + Interrupt-driven SCSI Data bus for Read & Write block routines
    + Low-Level Hardware register access for GPIO manipulation
    + Initial Optical Drive Emulation ported from TinySCSIEmu
    + Additional Mode Sense / Mode Select work to enable booting OpenVMS and Digital UNIX from CD or HD
    + Per-ID Inquiry Response editing via [CH]Dxx_xxx.cfg files instead of SCSI_CONFIG.TXT (same format)
    + Images should now be named CDxx_xxx.img or HDxx_xxx.img instead of HDxx_xxx.hda
2021-11-30 Configuration CLI, performance tweaks, stability improvements, tested on GreenSCSI v1.0 Minimum Viable Product (MVP) PCB
    [cmd.ino, config.h, defaults.ino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]
2022-06-11 File allocation fix
    mkimg would create files 1/1048576 in size compared to the request.
    [cmd.ino]
2022-06-11 Control channel framework
    Building the framework for communicating with the GreenSCSI command line over the SCSI bus.
2022-06-11 Constant consistency
    Cleaning up "Magic Values" and replacing them with defined constants.
    misc fixes.
    [defaults.ino, disk.ino, general.ino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]
2022-06-11 Tape Fixes
    Fixing various tape commands
    [tape.ino]
2022-06-12 3D Printed Case
    [GreenSCSI-bottom.stl, GreenSCSI-top.stl]
2022-06-12 MVP Edition Hardware
    Minimum Viable Product schematic, PCB layout & Gerbers.
    [GreenSCSI.kicad_pcb, GreenSCSI.sch]
2022-06-12 Schematic for MVP
2022-10-15 preAllocate fail
    preAllocate has angered the TrackZero and must be punished, out with preAllocate, in with writing zeros 512 bytes at a time.
    [cmd.ino]
2024-09-30 Fix selftest table to check all the pins, not just I/O and DB0
    [greenscsi.ino]
2025-09-15 Fixed build issues with conflicting DBP macros
    [dump.ino, greenscsi.ino, scsibus.ino]

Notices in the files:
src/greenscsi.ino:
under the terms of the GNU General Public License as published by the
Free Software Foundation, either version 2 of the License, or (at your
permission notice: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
